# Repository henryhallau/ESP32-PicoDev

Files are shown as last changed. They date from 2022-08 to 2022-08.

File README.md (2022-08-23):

# ESP32-PicoDev 1.0
A small project, mainly built for creating a prototype for my Smartwatch (more coming on that later).
It was created in KiCad, and this is the format of the project files.


A rendered version of the board

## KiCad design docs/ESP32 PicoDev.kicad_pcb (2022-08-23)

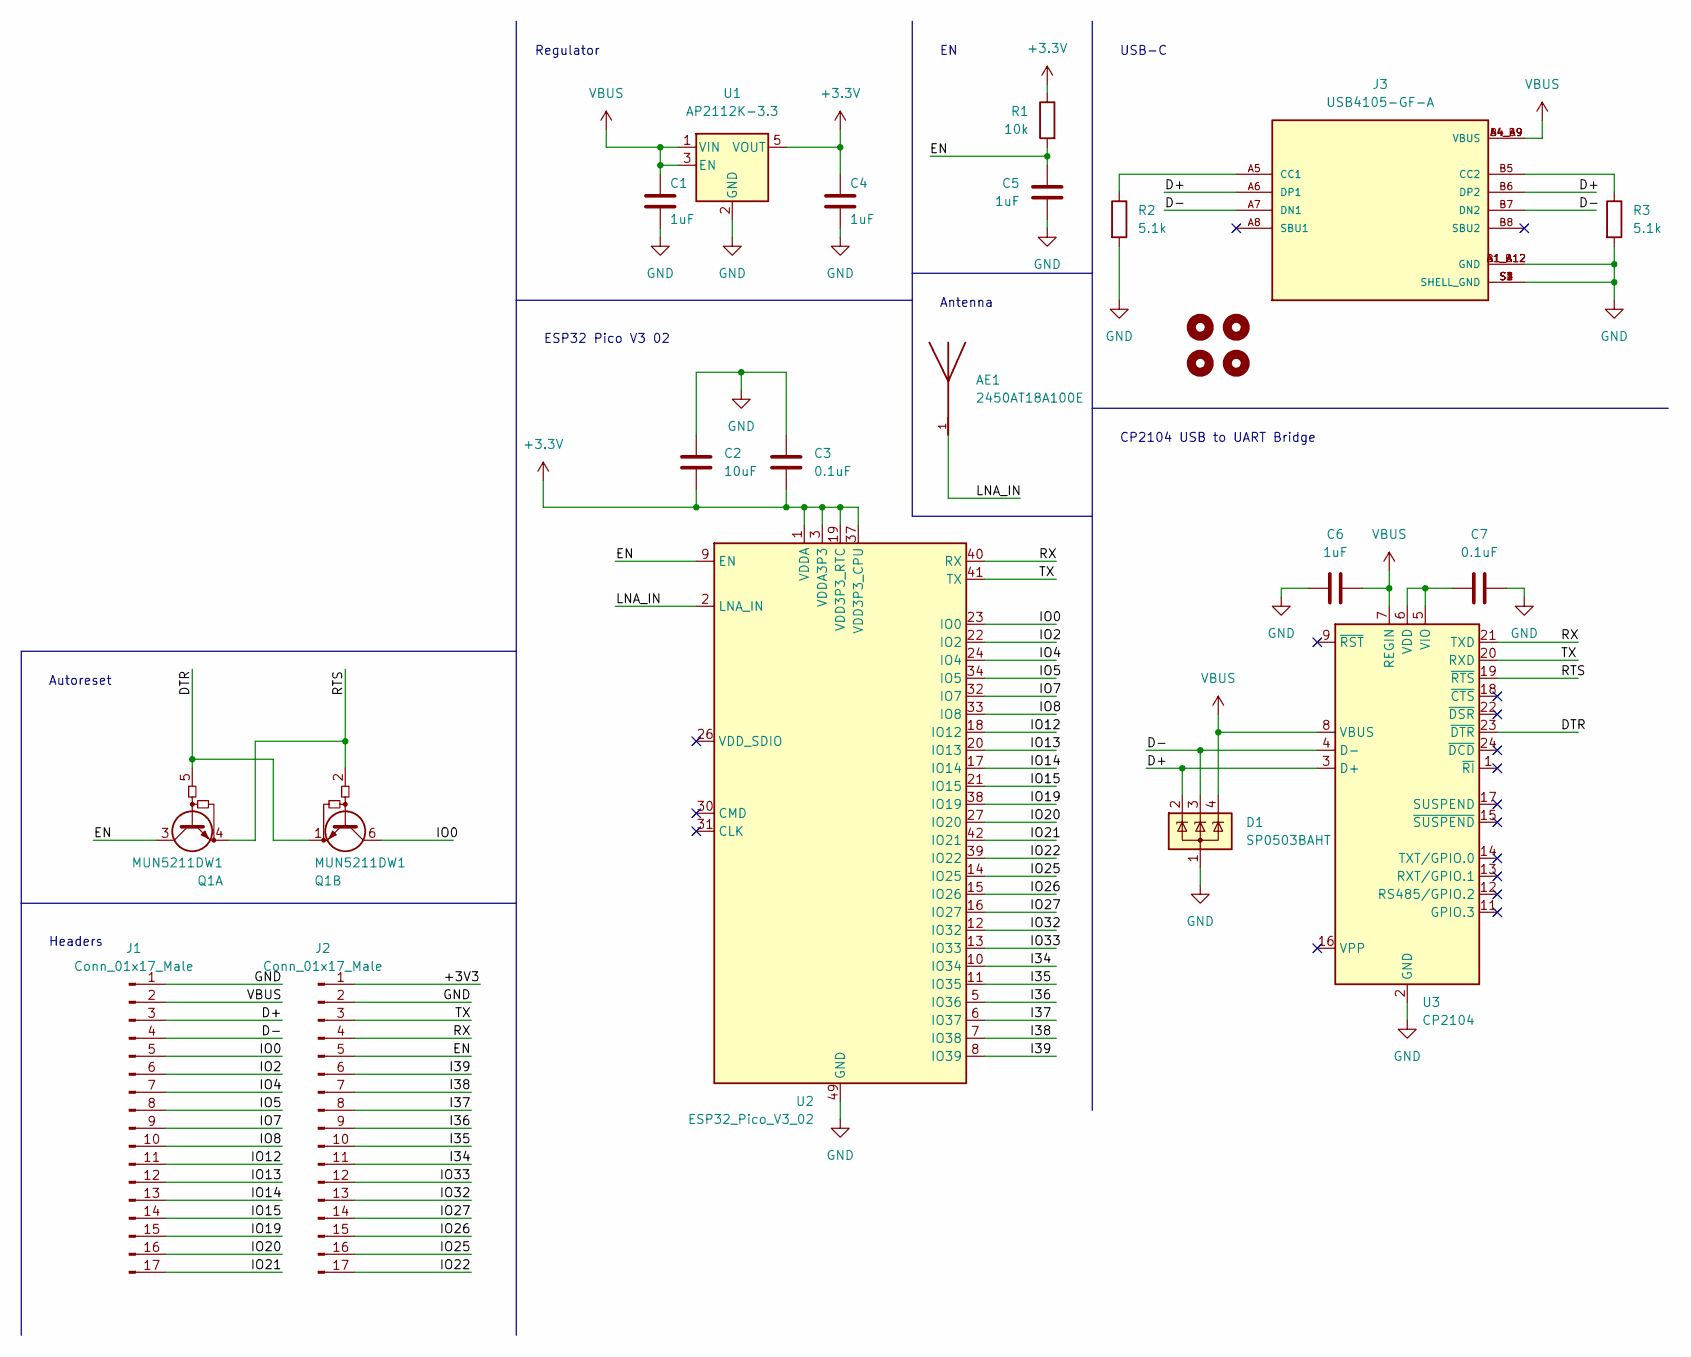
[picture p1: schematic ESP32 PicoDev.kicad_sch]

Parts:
AE1: 2450AT18A100E; ANTC3216X140N; PARTREV 1.3
C1, C4, C5, C6: 1uF; C_0603_1608Metric
C2: 10uF; C_0603_1608Metric
C3, C7: 0.1uF; C_0603_1608Metric
D1: SP0503BAHT; SOT-143
H1, H2, H3, H4: MountingHole; MountingHole2.54
J1, J2: Conn_01x17_Male; PinHeader_1x17_P2.54mm_Vertical
J3: USB4105-GF-A; GCT_USB4105-GF-A; PARTREV A3
Q1: MUN5211DW1; SOT-363_SC-70-6
R1: 10k; R_0603_1608Metric
R2, R3: 5.1k; R_0603_1608Metric
U1: AP2112K-3.3; SOT-23-5
U2: ESP32_Pico_V3_02; QFN-48-1EP_7x7mm_P0.5mm_EP5.3x5.3mm
U3: CP2104; QFN-24-1EP_4x4mm_P0.5mm_EP2.6x2.6mm

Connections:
/D+: D1.2 (K), J1.3, J3.A6 (DP1), J3.B6 (DP2), U3.3 (D+)
/D-: D1.3 (K), J1.4, J3.A7 (DN1), J3.B7 (DN2), U3.4 (D-)
/DTR: Q1.1 (E2), Q1.5 (B1), U3.23 (~DTR)
/EN: C5.1, J2.5, Q1.3 (C1), R1.2, U2.9 (EN)
/I34: J2.11, U2.10 (IO34)
/I35: J2.10, U2.11 (IO35)
/I36: J2.9, U2.5 (IO36)
/I37: J2.8, U2.6 (IO37)
/I38: J2.7, U2.7 (IO38)
/I39: J2.6, U2.8 (IO39)
/IO0: J1.5, Q1.6 (C2), U2.23 (IO0)
/IO2: J1.6, U2.22 (IO2)
/IO4: J1.7, U2.24 (IO4)
/IO5: J1.8, U2.34 (IO5)
/IO7: J1.9, U2.32 (IO7)
/IO8: J1.10, U2.33 (IO8)
/IO12: J1.11, U2.18 (IO12)
/IO13: J1.12, U2.20 (IO13)
/IO14: J1.13, U2.17 (IO14)
/IO15: J1.14, U2.21 (IO15)
/IO19: J1.15, U2.38 (IO19)
/IO20: J1.16, U2.27 (IO20)
/IO21: J1.17, U2.42 (IO21)
/IO22: J2.17, U2.39 (IO22)
/IO25: J2.16, U2.14 (IO25)
/IO26: J2.15, U2.15 (IO26)
/IO27: J2.14, U2.16 (IO27)
/IO32: J2.13, U2.12 (IO32)
/IO33: J2.12, U2.13 (IO33)
/LNA_IN: AE1.1, U2.2 (LNA_IN)
/RTS: Q1.2 (B2), Q1.4 (E1), U3.19 (~RTS)
/RX: J2.4, U2.40 (RX), U3.21 (TXD)
/TX: J2.3, U2.41 (TX), U3.20 (RXD)
GND: C1.2, C2.1, C3.1, C4.2, C5.2, C6.1, C7.2, D1.1 (A), J1.1, J2.2, J3.A1_B12 (GND), J3.B1_A12 (GND), J3.S1 (SHELL_GND), J3.S2 (SHELL_GND), J3.S3 (SHELL_GND), J3.S4 (SHELL_GND), R2.2, R3.2, U1.2 (GND), U2.49 (GND), U3.2 (GND), U3.25 (GND)
unnamed: C7.1, U3.5 (VIO), U3.6 (VDD)
unnamed: J3.A5 (CC1), R2.1
unnamed: J3.B5 (CC2), R3.1
VBUS: C1.1, C6.2, D1.4 (K), J1.2, J3.A4_B9 (VBUS), J3.B4_A9 (VBUS), U1.1 (VIN), U1.3 (EN), U3.7 (REGIN), U3.8 (VBUS)

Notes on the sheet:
CP2104 USB to UART Bridge
Antenna
Regulator
USB-C
Headers
ESP32 Pico V3 02
Autoreset

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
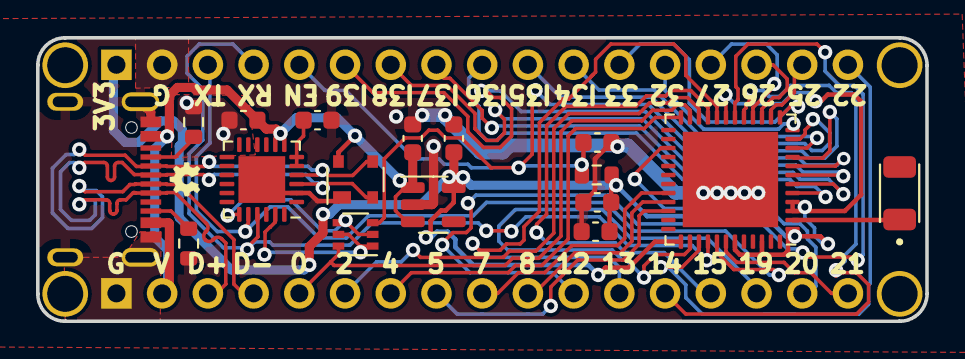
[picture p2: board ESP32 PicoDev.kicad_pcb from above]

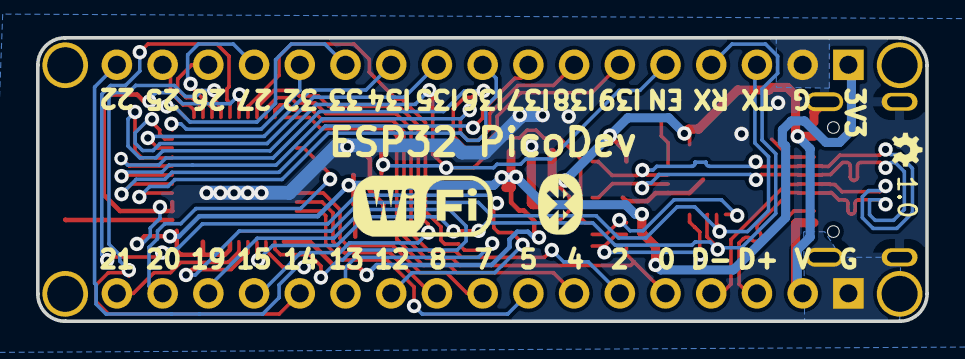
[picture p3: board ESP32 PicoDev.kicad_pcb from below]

Board: 2 copper layers, 49.4 x 15.7 mm, 23 parts (2 on the bottom side), 39 nets.
